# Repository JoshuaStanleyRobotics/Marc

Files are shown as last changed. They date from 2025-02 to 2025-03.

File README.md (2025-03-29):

# Marc
Thumbnail (Final)
This repository includes the CAD (.step and .f3d) and code (.ino) files for Marc, an Arduino powered remote control rolling cube robot.

The CAD and code for the remote control can be found in its own repository at https://github.com/JoshuaStanleyRobotics/Robot-Remote

A video outlining the design and assembly of Marc can be found here: https://youtu.be/nQgU45AvXcA

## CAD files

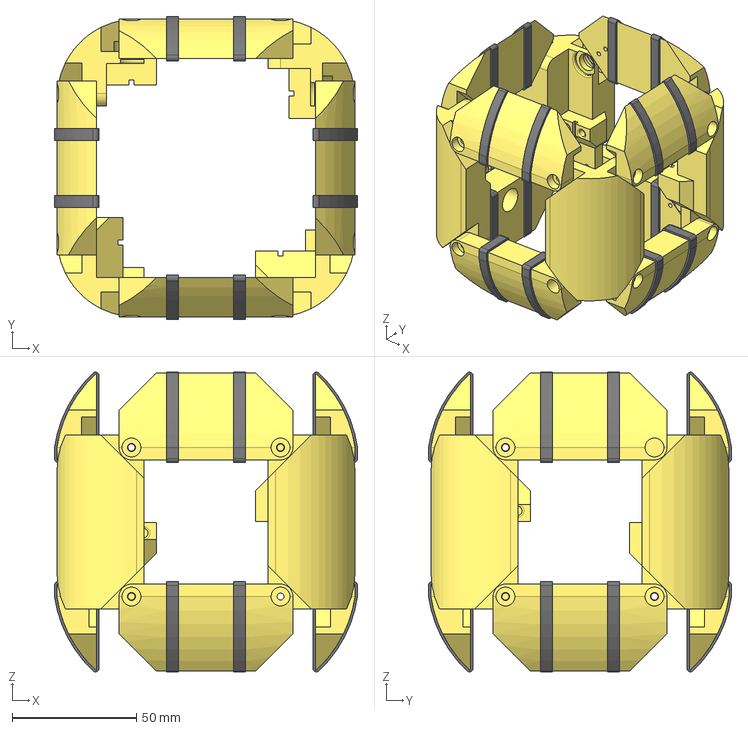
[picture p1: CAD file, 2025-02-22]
CAD/Marc.step
122.0 x 122.0 x 120.7 mm

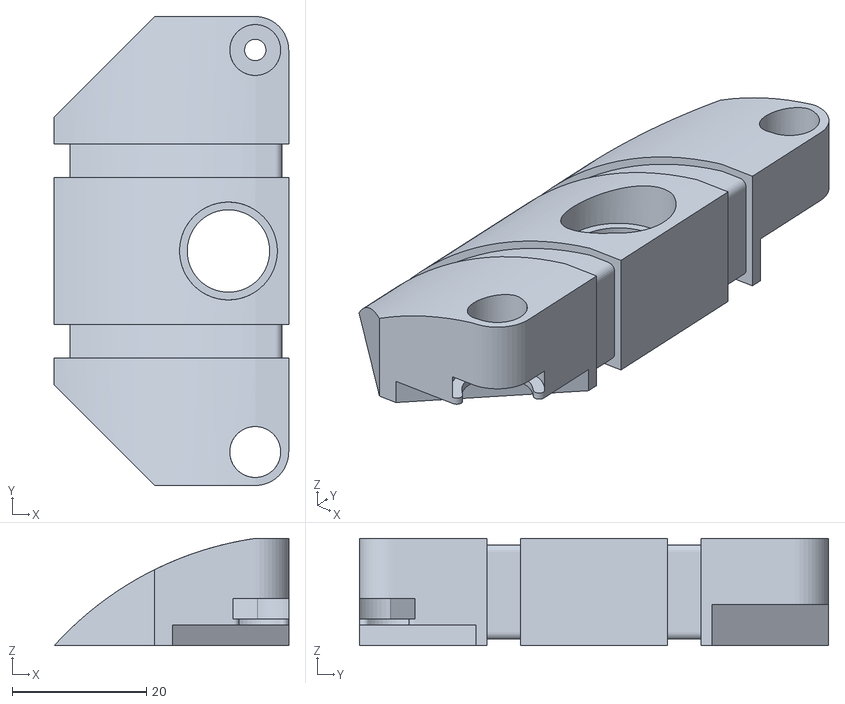
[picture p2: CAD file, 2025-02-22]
STLs/Button Link (Qty 1).stl
35.0 x 70.0 x 16.0

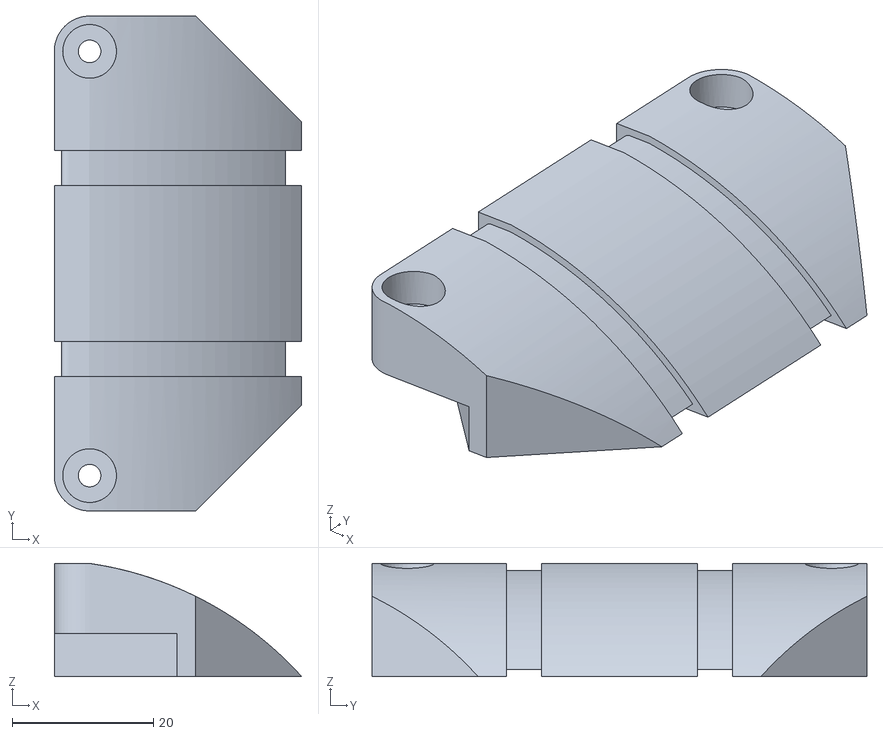
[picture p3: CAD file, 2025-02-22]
STLs/Passive Link (Qty 2).stl
35.0 x 70.0 x 16.0

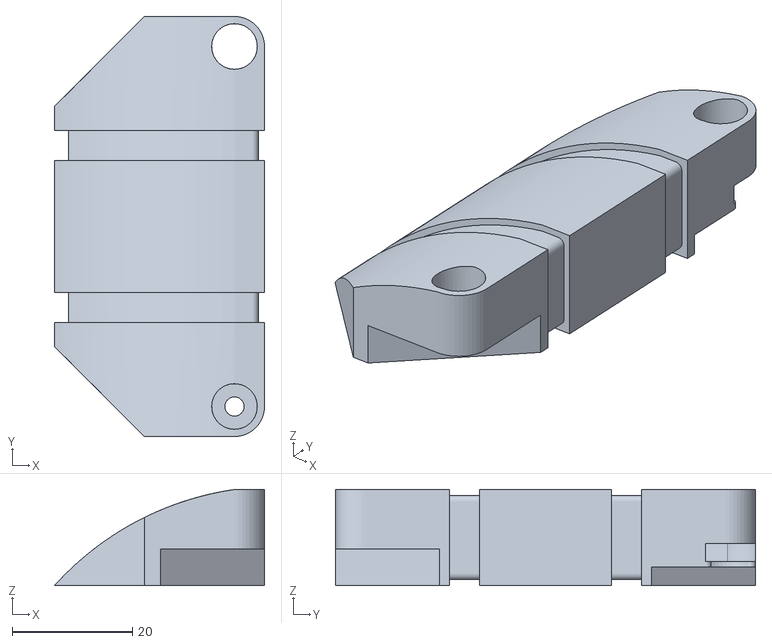
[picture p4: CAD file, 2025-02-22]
STLs/Actuated Link-A (Qty 2).stl
35.0 x 70.0 x 16.0

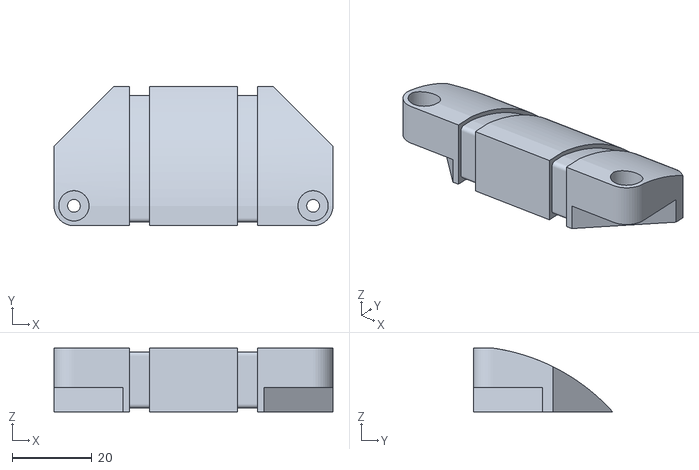
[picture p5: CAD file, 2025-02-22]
STLs/Control Board Link (Qty 1).stl
70.0 x 35.0 x 16.0

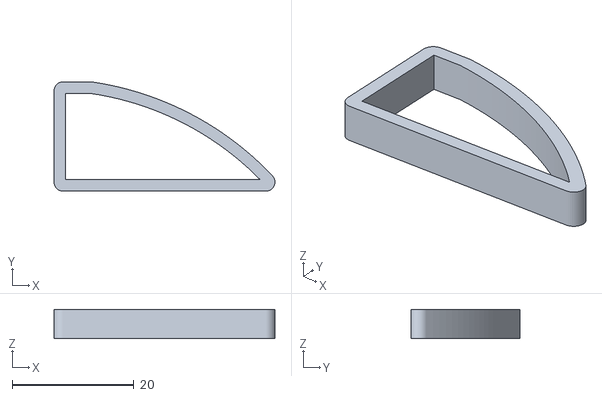
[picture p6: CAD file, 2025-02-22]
STLs/TPU Bumper (Qty 16).stl
36.4 x 18.0 x 4.80

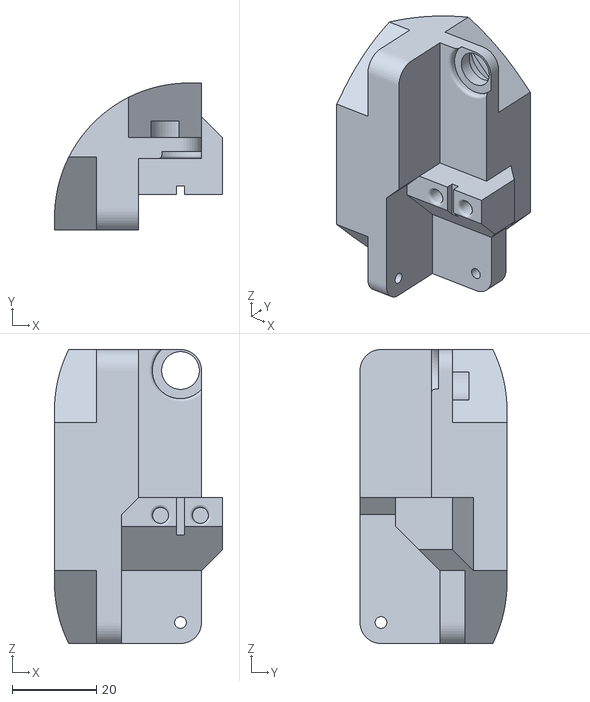
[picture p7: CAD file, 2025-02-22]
STLs/Servo Link-A (Qty 2).stl
40.0 x 35.0 x 70.0

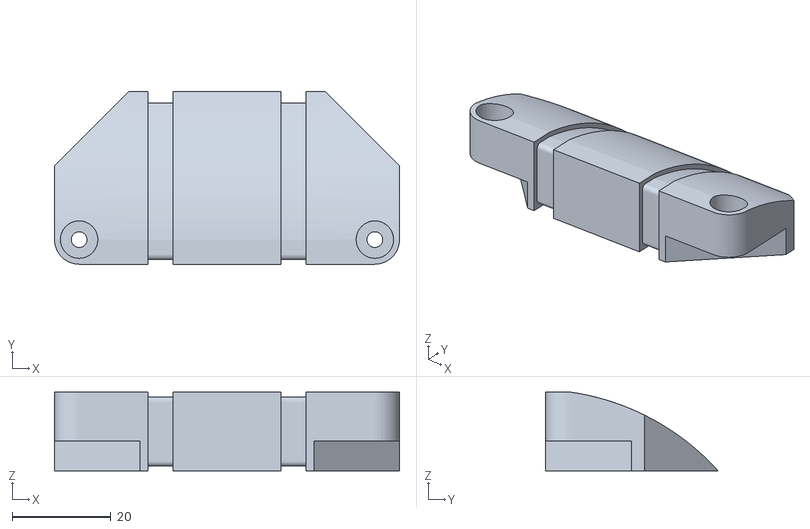
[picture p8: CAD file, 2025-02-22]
STLs/Battery Link (Qty 1).stl
70.0 x 35.0 x 16.0

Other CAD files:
STLs/Actuated Link-B (Qty 1).stl
STLs/Servo Link-B (Qty 2).stl
CAD/Marc.f3d

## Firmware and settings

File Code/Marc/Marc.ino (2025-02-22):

/*
   Description: This program is used to control a Multi-directional Articulaed Rolling Cube robot with IMU feedback

        Wiring: The required components are 4x MG995 servos, a NRF24L01 radio module, and a Seeed XIAO nRF52840 Sense microcontroller (or suitable microcontroller and IMU replacement)
        The servos are connected with brown wires to GND, red wires to VCC, and orange wires to D0-D4
        The NRF24L01 is connected 3.3V to 3v3, GND to GND, CSN to D7, MOSI to D10, CE to D6, SCK to D8, MISO to D9
*/

//Libraries
#include "Servo.h"
Servo servo[4];

#include "SPI.h"
#include "RF24.h"
RF24 radio(6, 7);

#include "LSM6DS3.h"
LSM6DS3 IMU(I2C_MODE, 0x6A);
#include "Wire.h"

//Variables
byte data[] = {0, 0, 0, 0, 0, 0, 0, 0, 0, 0};
int xDir = 0;
int yDir = 0;
int duration = 0;

//Constants
const byte chan[6] = "00007";                                                                       //Radio channel used
const int acute[] = {40, 144, 146, 45};                                                             //Calibration array defining the position of each servo at its minimum angle
const int obtuse[] = {141, 41, 48, 139};                                                            //Calibration array defining the position of each servo at its maximum angle

void setup() {
  Serial.begin(9600);                                                                               //Begin serial communication
  Serial.println("Serial Communication Initialized");

  radio.begin();                                                                                    //Begin radio communication
  radio.openReadingPipe(1, chan);
  radio.setPALevel(RF24_PA_MIN);
  radio.startListening();
  Serial.println("Radio Communication Initialized");

  IMU.begin();                                                                                      //Initialize Inertial Measurement Unit
  Serial.println("Inertial Measurement Unit Initialized");

  for (int i = 0; i < 4; i++) {                                                                     //Initialize servos
    servo[i].attach(i);
    servo[i].write(map(90, 45, 135, acute[i], obtuse[i]));
  }
  Serial.println("Servo Attached");

  delay(250);
  Serial.println("Running");
}

void loop() {
  if (radio.available()) {
    radio.read(&data, sizeof(data));                                                                //Read in radio data if available

    if (data[1] != 0) {                                                                             //Forward and reverse controlled by front to back motion of left joystick
      if (data[1] > 127) {                                                                          //Rolling forward
        for (int i = 2; i < 4; i++) servo[i].write(acute[i]);
        delay(450);
        for (int i = 2; i < 4; i++) servo[i].write(obtuse[i]);
        delay(450);
      }
      else {                                                                                        //Rolling backward
        for (int i = 2; i < 4; i++) servo[i].write(obtuse[i]);
        delay(450);
        for (int i = 2; i < 4; i++) servo[i].write(acute[i]);
        delay(450);
      }
    }
    else if (data[0] != 0) {                                                                        //Side to side controlled by left to right motion of left joystick
      if (data[0] > 127) {                                                                          //Rolling right
        for (int i = 0; i < 2; i++) servo[i].write(acute[i]);
        delay(450);
        for (int i = 0; i < 2; i++) servo[i].write(obtuse[i]);
        delay(450);
      }
      else {                                                                                        //Rolling left
        for (int i = 0; i < 2; i++) servo[i].write(obtuse[i]);
        delay(450);
        for (int i = 0; i < 2; i++) servo[i].write(acute[i]);
        delay(450);
      }
    }
    else {                                                                                          //No motion is commanded
      for (int i = 0; i < 4; i++) servo[i].write((acute[i] + obtuse[i]) / 2);                       //Set the cube to its neutral shape
      delay(250);

      if (abs(IMU.readFloatAccelZ()) > 0.8) {                                                       //If the cube is on its front or back face, roll forward onto the top or bottom
        for (int i = 2; i < 4; i++) servo[i].write(acute[i]);
        delay(350);
      }
      else if (abs(IMU.readFloatAccelX()) > 0.8) {                                                  //If the cube is on its left or right face, roll sideways onto the top or bottom
        for (int i = 0; i < 2; i++) servo[i].write(acute[i]);
        delay(350);
      }
    }
    radio.flush_rx();
  }
  delay(5);
}
